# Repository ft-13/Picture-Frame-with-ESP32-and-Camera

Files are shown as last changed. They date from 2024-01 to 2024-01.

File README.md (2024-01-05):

# Picture-Frame-with-ESP32-and-Camera
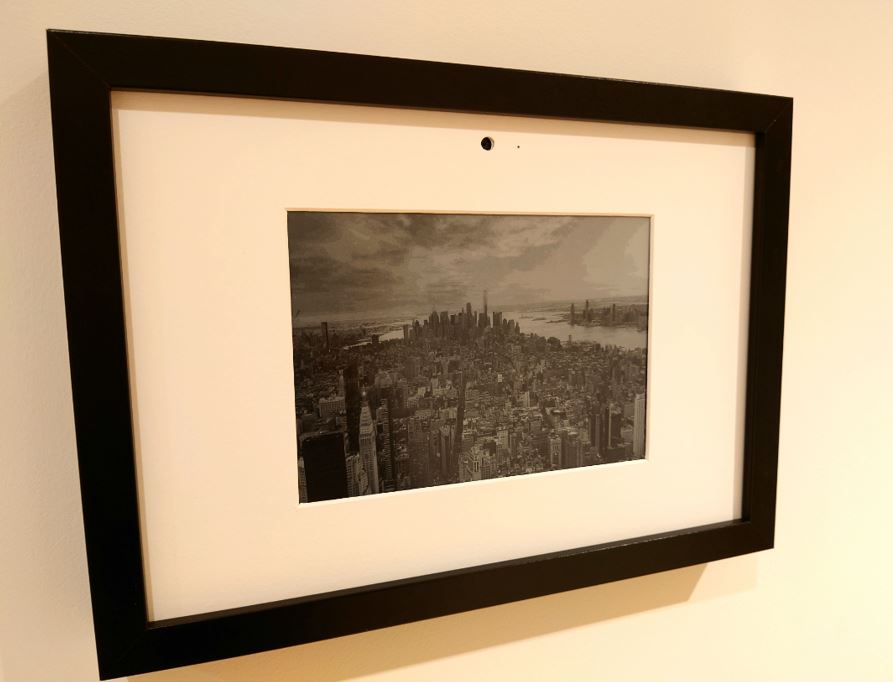
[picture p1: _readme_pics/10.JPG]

The picture frame consists of Firebeetle2 (ESP32-S3) with OV2640 camera, epaper display, powerbank and a self-desined carrier PCB. The whole electronic is mounted on a 3D printed insert. There are 3 Hall sensors attached to the wood of picture frame: top, bottom left and bottom right. µSD card shield is mounted to the carrier PCB and makes it possible to save the camera picture or to load a picture. Using a magnet triggers one of the three Hall sensors and wakes up ESP32 from deep sleep. When the top Hall sensor is triggered, the picture frame takes a picture and sends it to the epeaper and the µSD card. If the left or right sensor is triggered, the previous or next image is loaded from the µSD card to the epeaper display.  
  
Special thanks go to my wife, who has always been very patient with my handicrafts :)



## Software
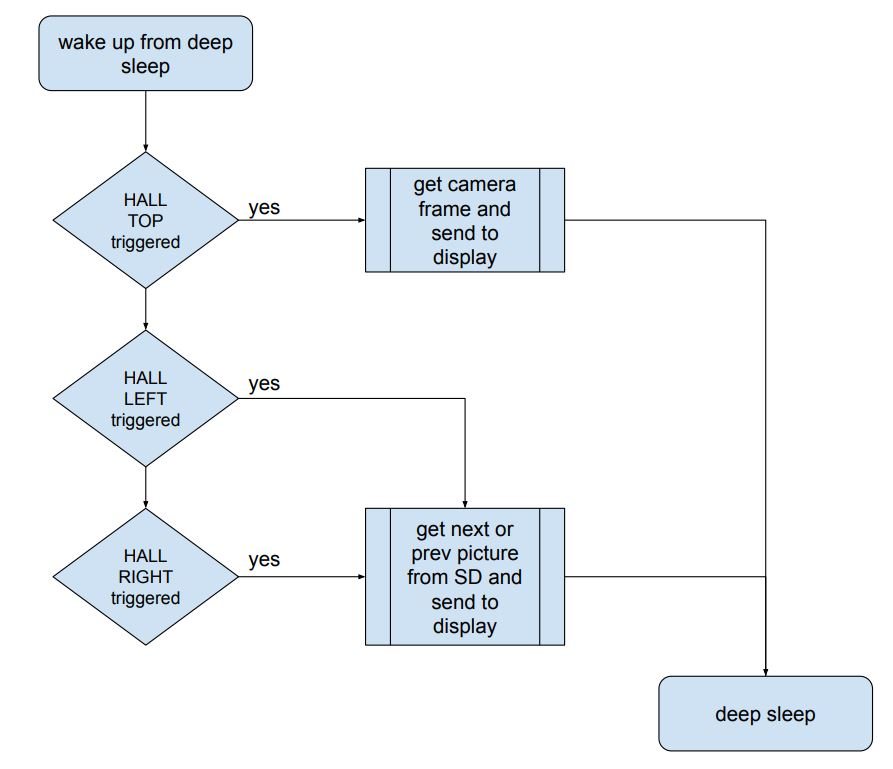
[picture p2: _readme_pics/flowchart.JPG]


## Hardware
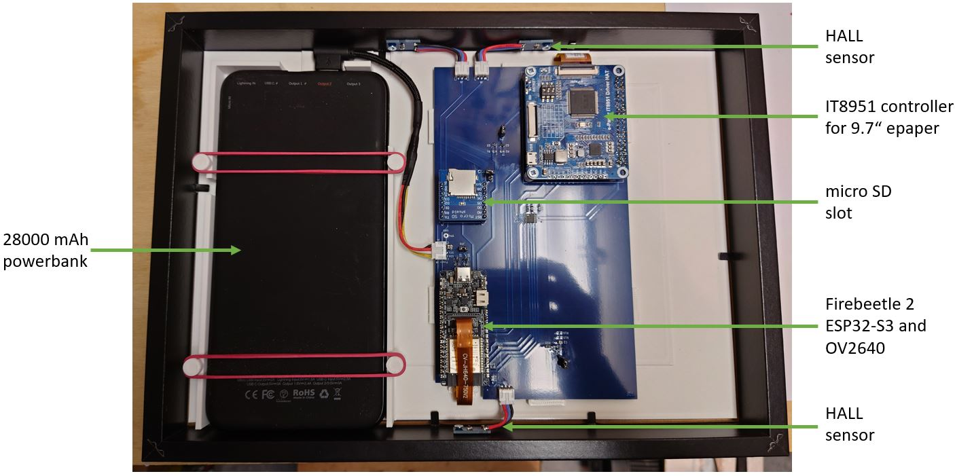
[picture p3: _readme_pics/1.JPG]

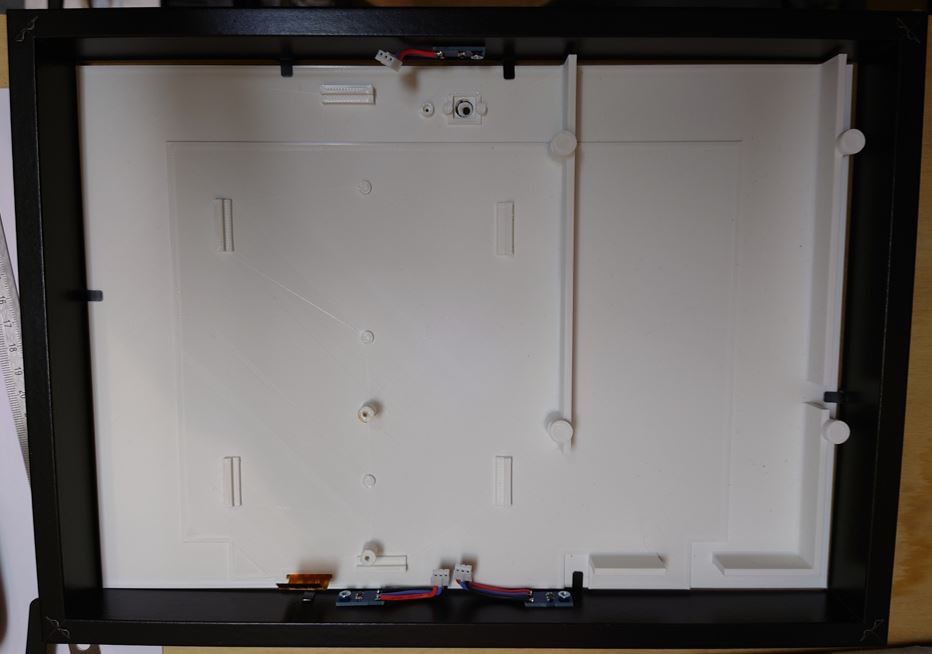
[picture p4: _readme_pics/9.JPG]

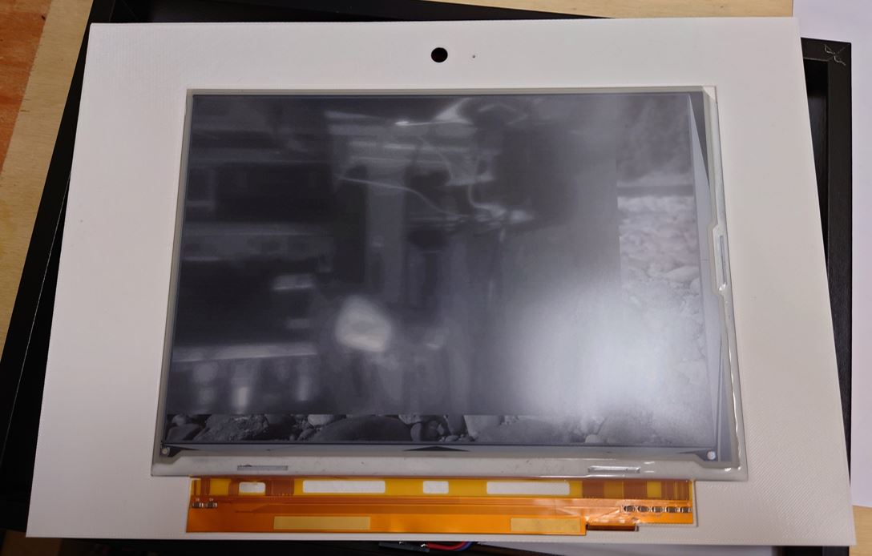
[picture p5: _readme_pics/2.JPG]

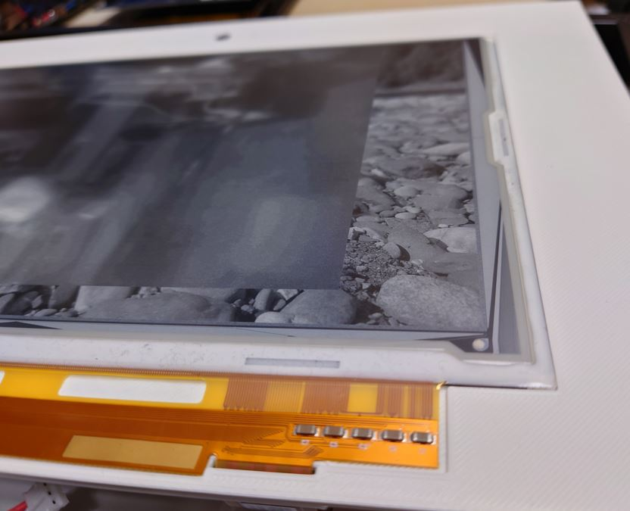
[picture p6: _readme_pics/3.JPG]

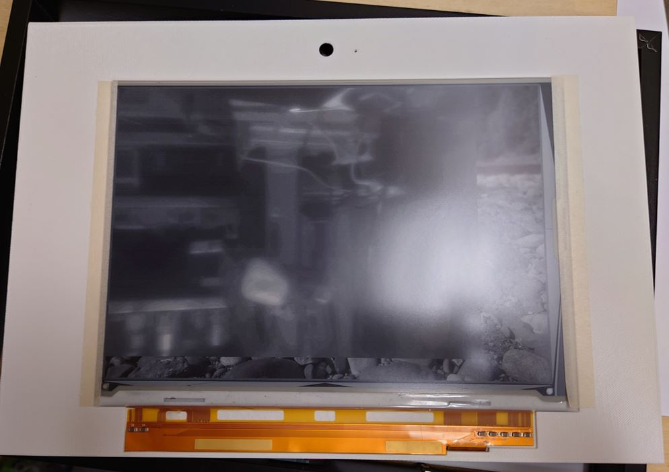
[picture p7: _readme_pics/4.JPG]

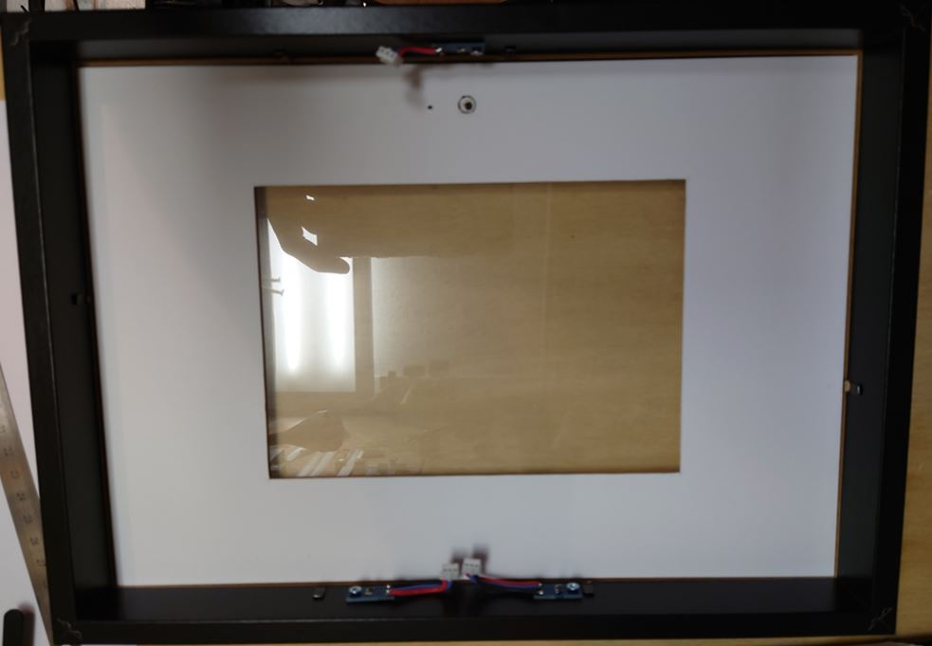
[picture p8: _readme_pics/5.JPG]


### BOM
Part | Description | Link 
--- | --- | ---
Firebeetle2 | ESP32-S3 8MB PSRAM and OV2640 camera | [dfrobot link](https://www.dfrobot.com/product-2677.html)
IT8951 display HAT | - | [Waveshare link](https://www.waveshare.com/9.7inch-e-paper-hat.htm)
epaper display | 1200x825, 9.7inch | [Waveshare datasheet](https://www.waveshare.com/w/upload/f/ff/9.7inch_E-paper_Specification.PDF)
µSD shield | D1 mini shield adapter | [AZ delivery link](https://www.az-delivery.de/products/micro-sd-card-adapter-shield)
Hall sensors | DRV5032FA TI | [TI datasheet](https://www.ti.com/lit/ds/symlink/drv5032.pdf?ts=1704351535372&ref_url=https%253A%252F%252Fwww.google.com%252F)
Analog Switch | TS3A5018PW TI | [TI datasheet](https://www.ti.com/lit/ds/symlink/ts3a5018.pdf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)
Powerbank | Charmast 26800mAh | [Amazon link](https://www.amazon.de/Charmast-Powerbank-Ladeger%C3%A4t-Eing%C3%A4ngen-Smartphones-Schwarz/dp/B073FJ9X2J)
Picture frame | Ikea black 21x30 cm | [Ikea link](https://www.ikea.com/de/de/p/ribba-rahmen-schwarz-60378396/)

### Powerbank
The powerbank has a hugh capacity of 26800mAh. When ESP32 is in deep sleep the entire electronic draws a current of <=2mA. If the current draw from powerbank is about <70mA the powerbank automatically turns off its outputs after 30 seconds. Then the electronic has no chance to power up unless the button of powerbank is pressed to switch it on again. I figured out that the powerbank has two DCDC converters: IP5306 and IP5310. Both chips can be configured via I2C. I found the I2C protocol of IP5306 on github: [github link](https://github.com/bheesma-10/IP5306_I2C) but no chance for IP5310. For IP5306 there is a register bit which can be set to tell the chip to stay on. Unfortunatelly this bit is not the same for IP5310. Why not using IP5306 instead of IP5310? Because I could get access only to I2C pins of IP5310 via charging state LEDs. The next problem is that IP5310 is responsible for battery charging.

I soldered I2C wires to the LEDs which are connected to IP5310 and tried to write to different registers and voila! Bit 7 of register 0x02 tells the chip to stay on.
What else? The powerbank on/off switch is connected to IP5306. As soon as IP5306 wakes up, it will wake up IP5310 via a transitor. Therefore I had to do some modifications on powerbank PCB. Now I can switch IP5310 off and on by pressing the power button of the powerbank (single push: ON, double push: OFF).

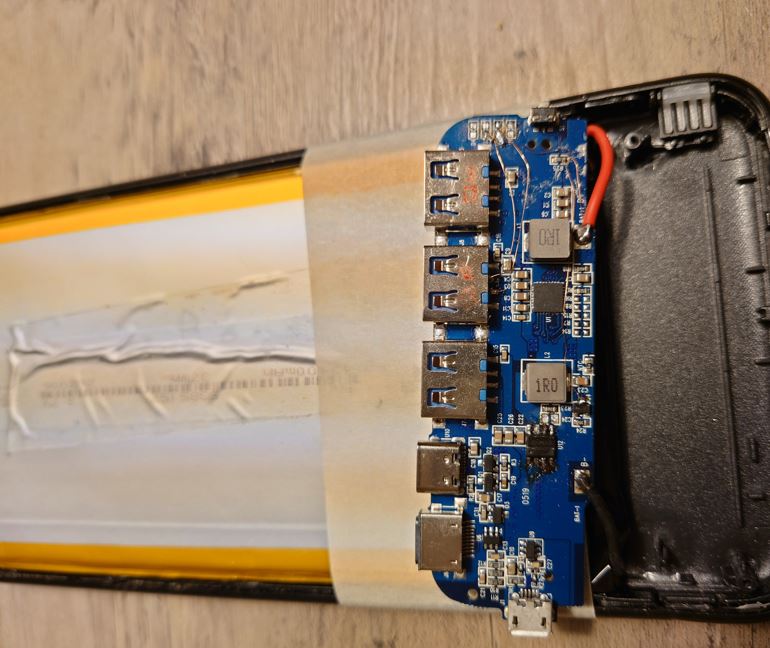
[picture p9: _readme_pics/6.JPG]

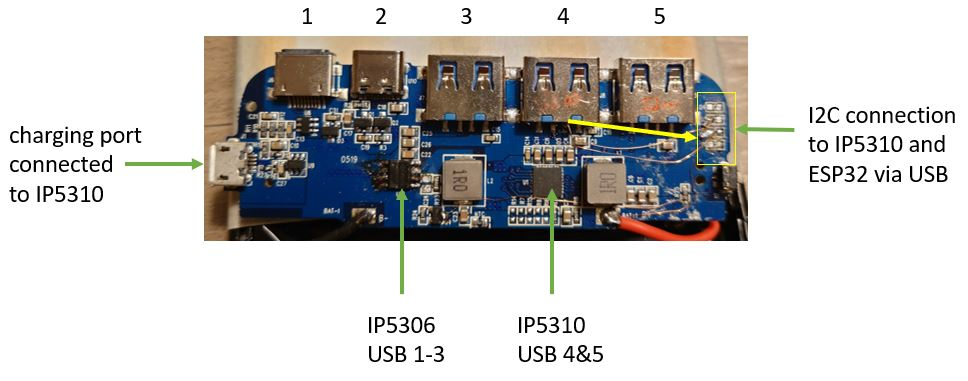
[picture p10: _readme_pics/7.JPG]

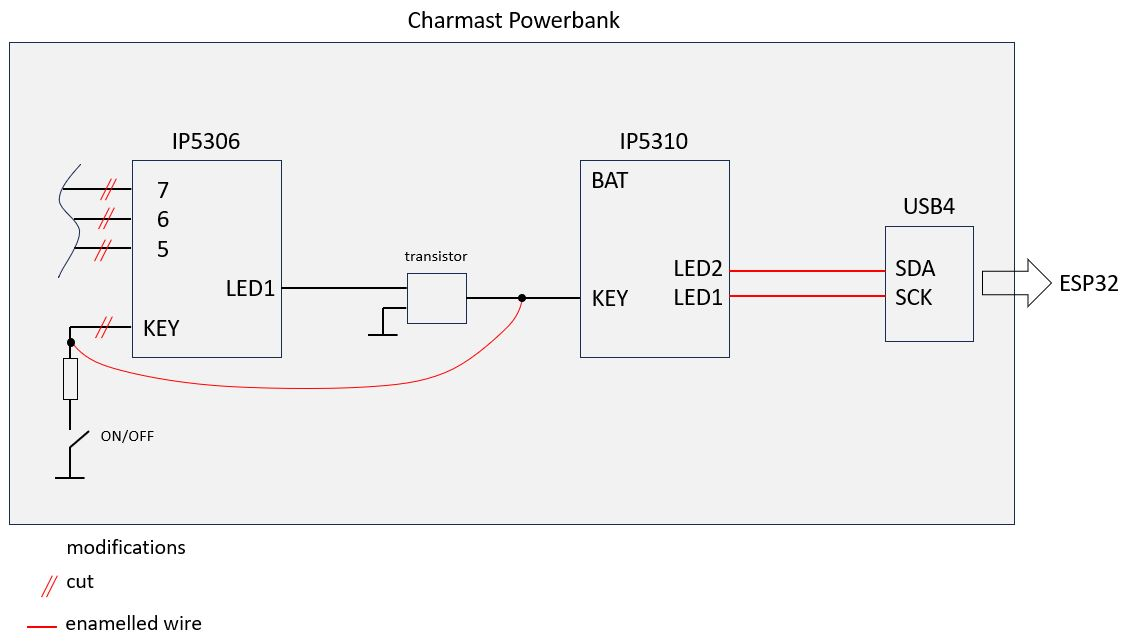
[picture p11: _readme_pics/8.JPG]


### Current Consumption
My goal was it that the powerbank lasts for about 1 year. Of course it depends on how many pictures do you take and how many picture do you load from µSD card.
In deep sleep mode the entire electronic (excluding powerbank) draws a current of about 344µA. Unfortunately, this is not the figure that can be used for the calculation. The IP5310 DCDC converter has a converter efficiency that drives the figure up at the end. That's why I measured the current consumption from the battery itself. The unloaded powerbank draws a current of 1.4mA and in loaded condition (334µA) the current consumption is about 2mA.
If I never took a photo, i.e. ESP32 is in deep sleep all the time, the power bank would last:
days = 26800mAh / 2mA / 24h = 558 days (1.5 years).

But lets make the calculation with some assumptions:  
(I have not yet made any exact measurements, so this is a simplified calculation)
- 1 picture per day and 2 µSD card read access' per day.
- take picture and send to display and µSD card: 300mA for 10s
- load picture from µSD card and send to display: 250mA for 8s
  
We need to know the average current consumption  
Iavg = (300mA * 10s + 250mA * 8s * 2 + 2mA * 3570s) / 3600s = 3.93mA  
to calculate how long the powerbank lasts  
days = 26800mAh / Iavg / 24h = 284 days.
  
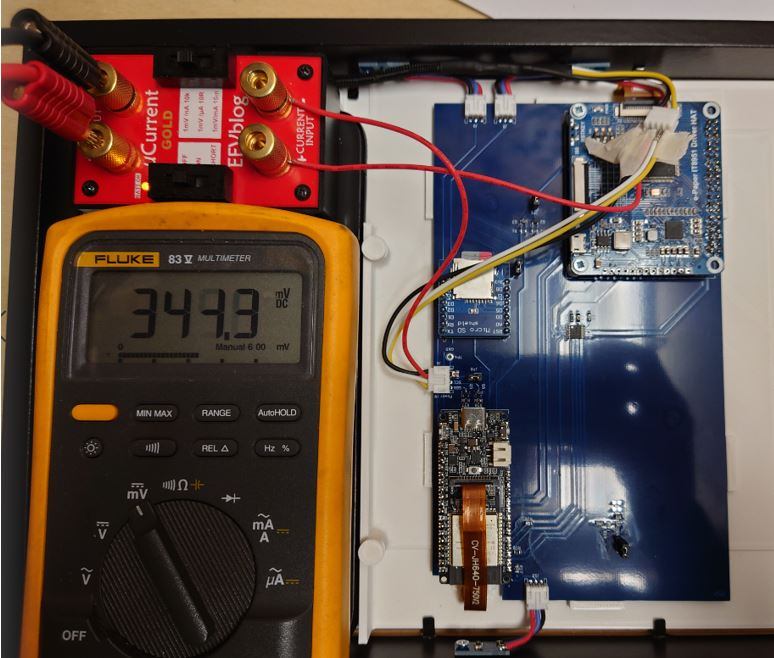
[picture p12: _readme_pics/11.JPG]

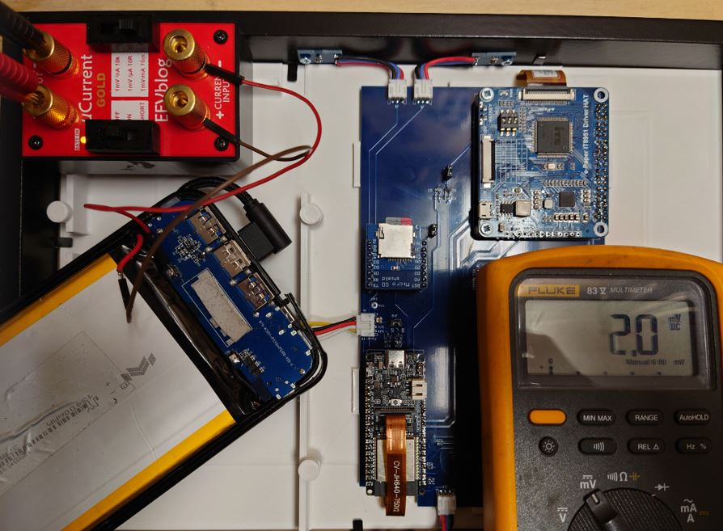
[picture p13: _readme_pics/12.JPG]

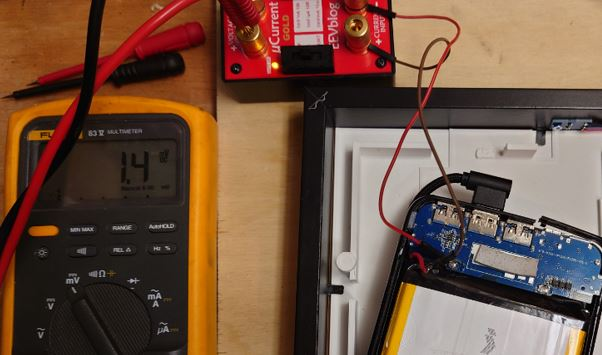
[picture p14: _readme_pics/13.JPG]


## FAQ
1. Why is the carrier PCB so hugh?  
   Firebeetle2 (Camera has short flex PCB) and IT8951 cannot not be postioned on the same side, as the flex PCB of epaper fills the entire bottom side. Therefore there is no space left where the camera could see through.
2. Why did you use Firebeetle2? What's so special about?  
   The Firebeetle2 has a DCDC Converter, which can be configured over I2C and can deactivate the power of the camera, thus bringing the power consumption of the camera to null.
3. Why is the size of the camera picture (XGA 1024x768) smaller than the available size of the display (1200x825)?  
   Because the passpartout cut-out of the picture frame has nearly the size of XGA. Of course I could have bought a passpartout with a larger cut-out, which I will do next.
4. If you have already designed your own PCB, why didn't you include a charging circuit instead of struggling with the power bank?  
   I didn't do much research but I couldn't find a suitable Li-Ion charging IC with integrated boost converter and pass through function.
   I also wanted to keep the development time as short as possible and do without non-SOICs, as I soldered the components on by hand.
   And it was also fun "hacking" the powerbank.
5. Why did you decide to use Hall sensors instead of switches, proximity sensors or even gesture recognition using the camera?  
   The current consumption of the Hall sensors is a maximum of 3.5µA per sensor, as other sensor technologies cannot keep up.
   I wanted to do without electromechanical switches, as the overall picture would not have been nice for me, apart from the fact that I couldn't find any very small built-in pushbuttons.
   Gesture recognition using the ESP camera would have increased power consumption and drastically reduced battery life.
   A capacitive proximity switch consisting of e.g. an AD7151/AD7156 and a capacitive foil would certainly have worked as well, if not more elegantly, but in this case I wanted to save costs as I had the Hall sensors lying around anyway.
6. In which format are the files saved on the SD card or in which format do they have to be?  
   The recorded image is saved as raw bytes with an ascending number and the file extension .txt. The file size is always exactly 768432 bytes (1024x768 pixels and 8bit/pixel). 
7. Is there a way to view the images on the SD card on a PC and is it possible to save images other than those taken by the camera itself?  
   Yes, both are possible. It is possible with the free tool magick e.g. In the repository folder "Software/2_pic_converter" there is a self-written python tool.
   This tool converts all jpg images in a folder and stores them in an "output" folder. These can then simply be copied to the SD card (with ascending number).
   With the command "magick -depth 8 -size 1024x768 gray:files_on_sd_card.txt result.jpg" the raw bytes can be converted back into a jpg image.
   The tool is currently very simple and does not yet have any terminal arguments etc.
8. AI generated pictures?  
   The next upgrade will be for my Raspberry Pi server to generate an image once a day from an AI on the internet and then send it to the picture frame via Wifi.

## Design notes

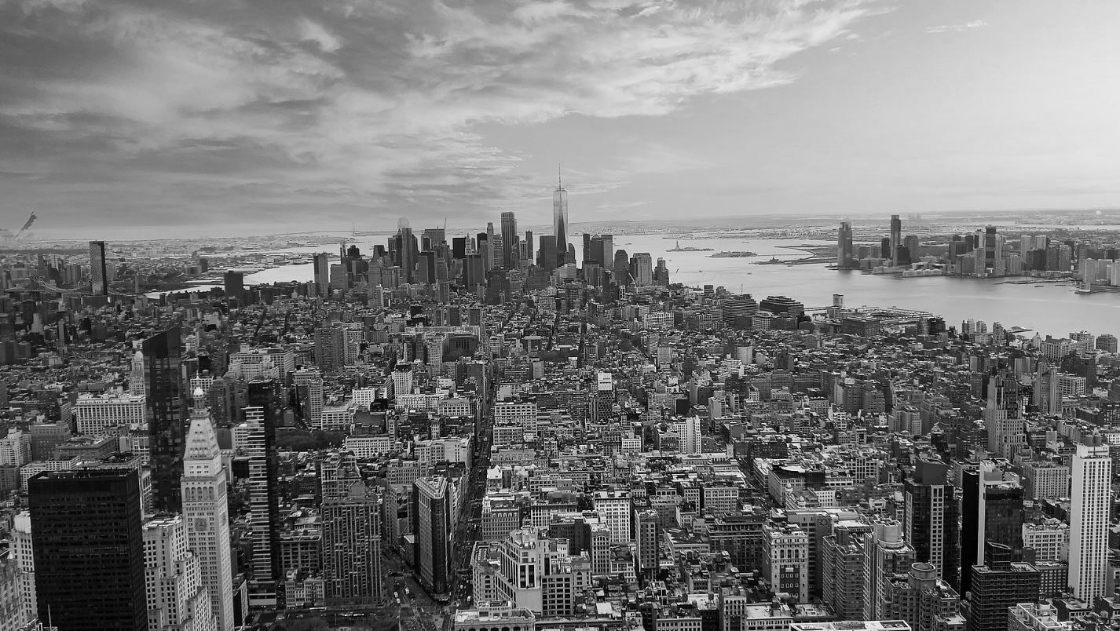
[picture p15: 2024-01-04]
Software/2_pic_converter/converter/manhatten_gray.JPG

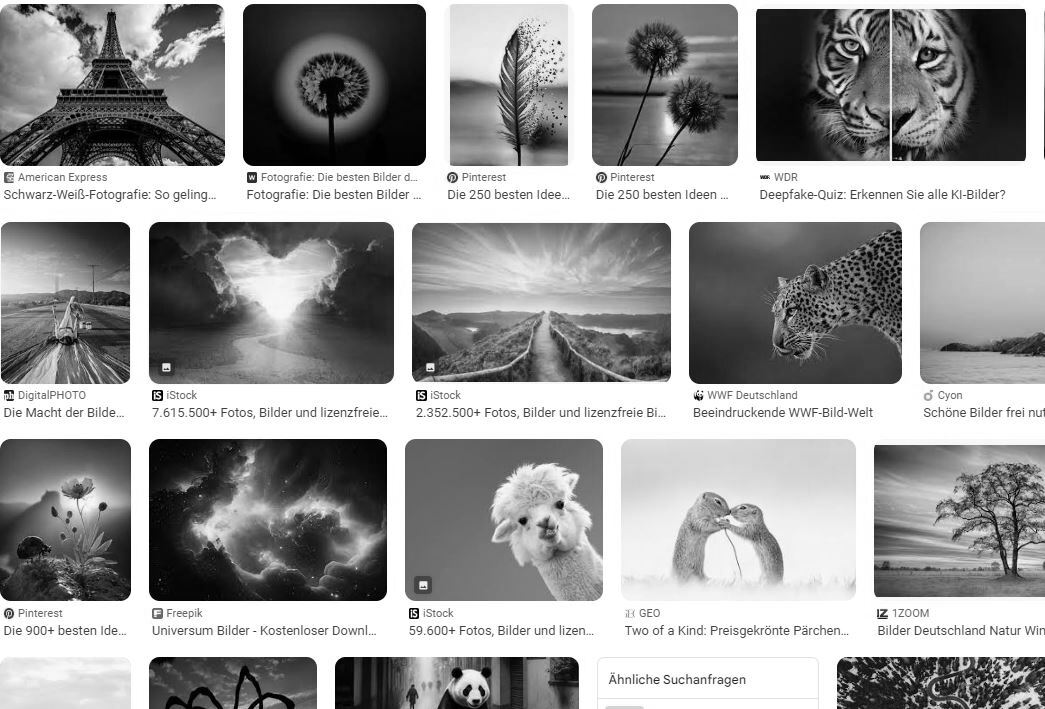
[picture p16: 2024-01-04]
Software/2_pic_converter/converter/google_pics_gray.JPG

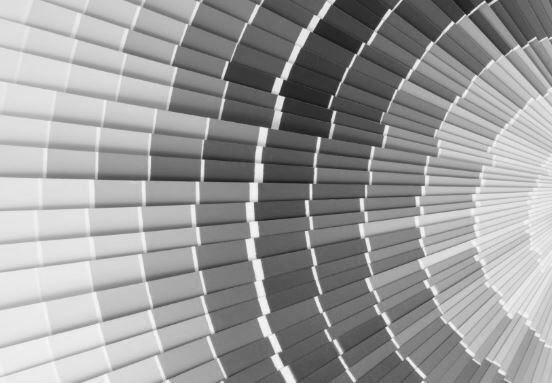
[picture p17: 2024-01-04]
Software/2_pic_converter/converter/color_palette_gray.JPG

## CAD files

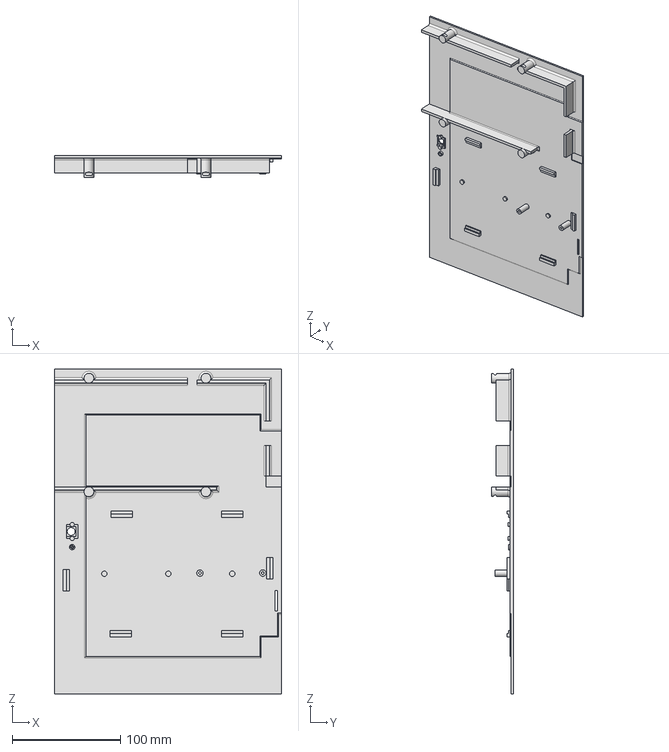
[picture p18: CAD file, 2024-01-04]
Hardware/step/display_holder.stp
210.0 x 20.0 x 300.0 mm

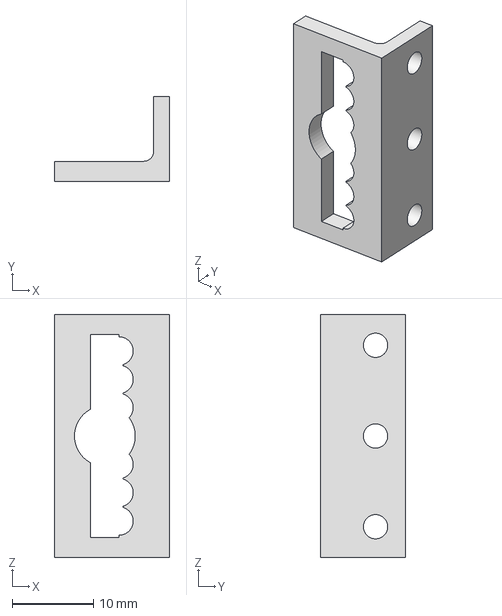
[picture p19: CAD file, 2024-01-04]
Hardware/step/screw_frame_holder.stp
14.3 x 10.5 x 30.0 mm

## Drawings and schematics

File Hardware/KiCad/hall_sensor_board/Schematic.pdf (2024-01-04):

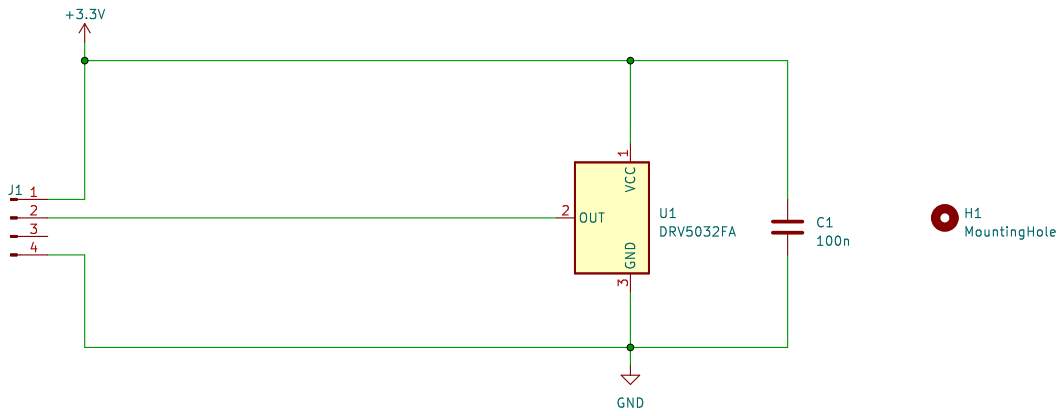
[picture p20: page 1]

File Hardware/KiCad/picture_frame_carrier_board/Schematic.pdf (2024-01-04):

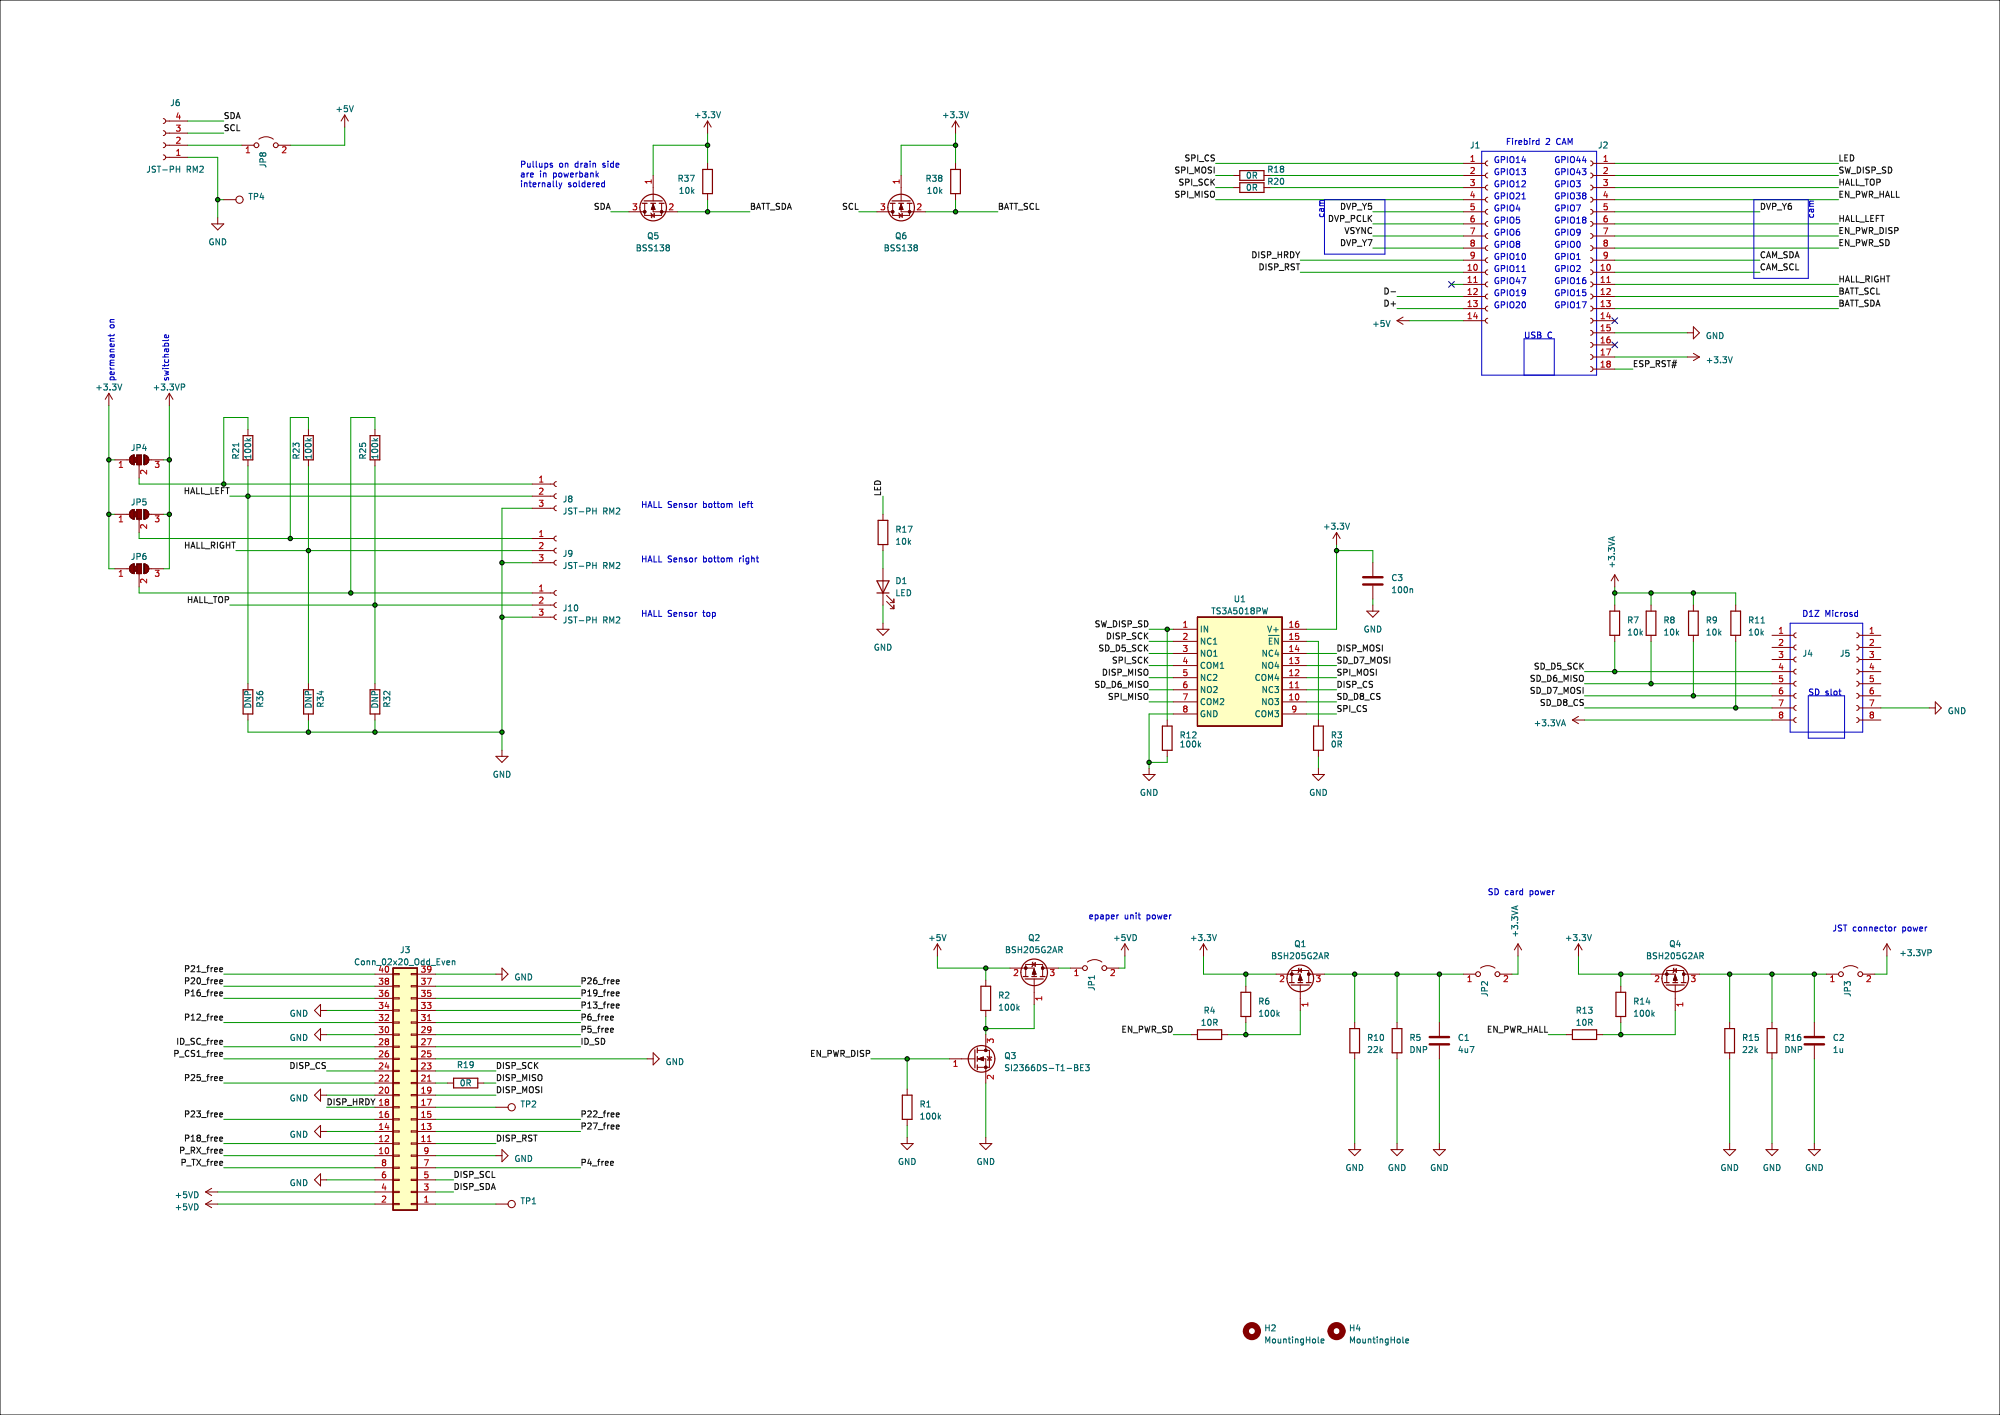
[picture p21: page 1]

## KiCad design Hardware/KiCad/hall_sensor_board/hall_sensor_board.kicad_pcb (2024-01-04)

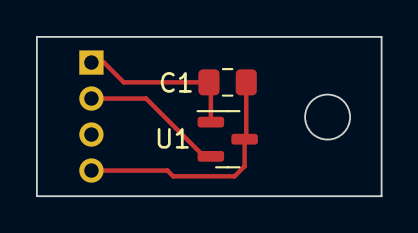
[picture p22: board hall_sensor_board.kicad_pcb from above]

Board: 2 copper layers, 19.2 x 8.9 mm, 3 parts (1 on the bottom side), 3 nets.

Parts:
C1: 100n; C_0805_2012Metric_Pad1.18x1.45mm_HandSolder
J1: Conn_01x04_Pin; PinHeader_1x04_P2.00mm_Horizontal
U1: DRV5032FA; SOT-23

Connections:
+3.3V: C1.1, J1.1, U1.1 (VCC)
GND: C1.2, J1.4, U1.3 (GND)
unnamed: J1.2, U1.2 (OUT)

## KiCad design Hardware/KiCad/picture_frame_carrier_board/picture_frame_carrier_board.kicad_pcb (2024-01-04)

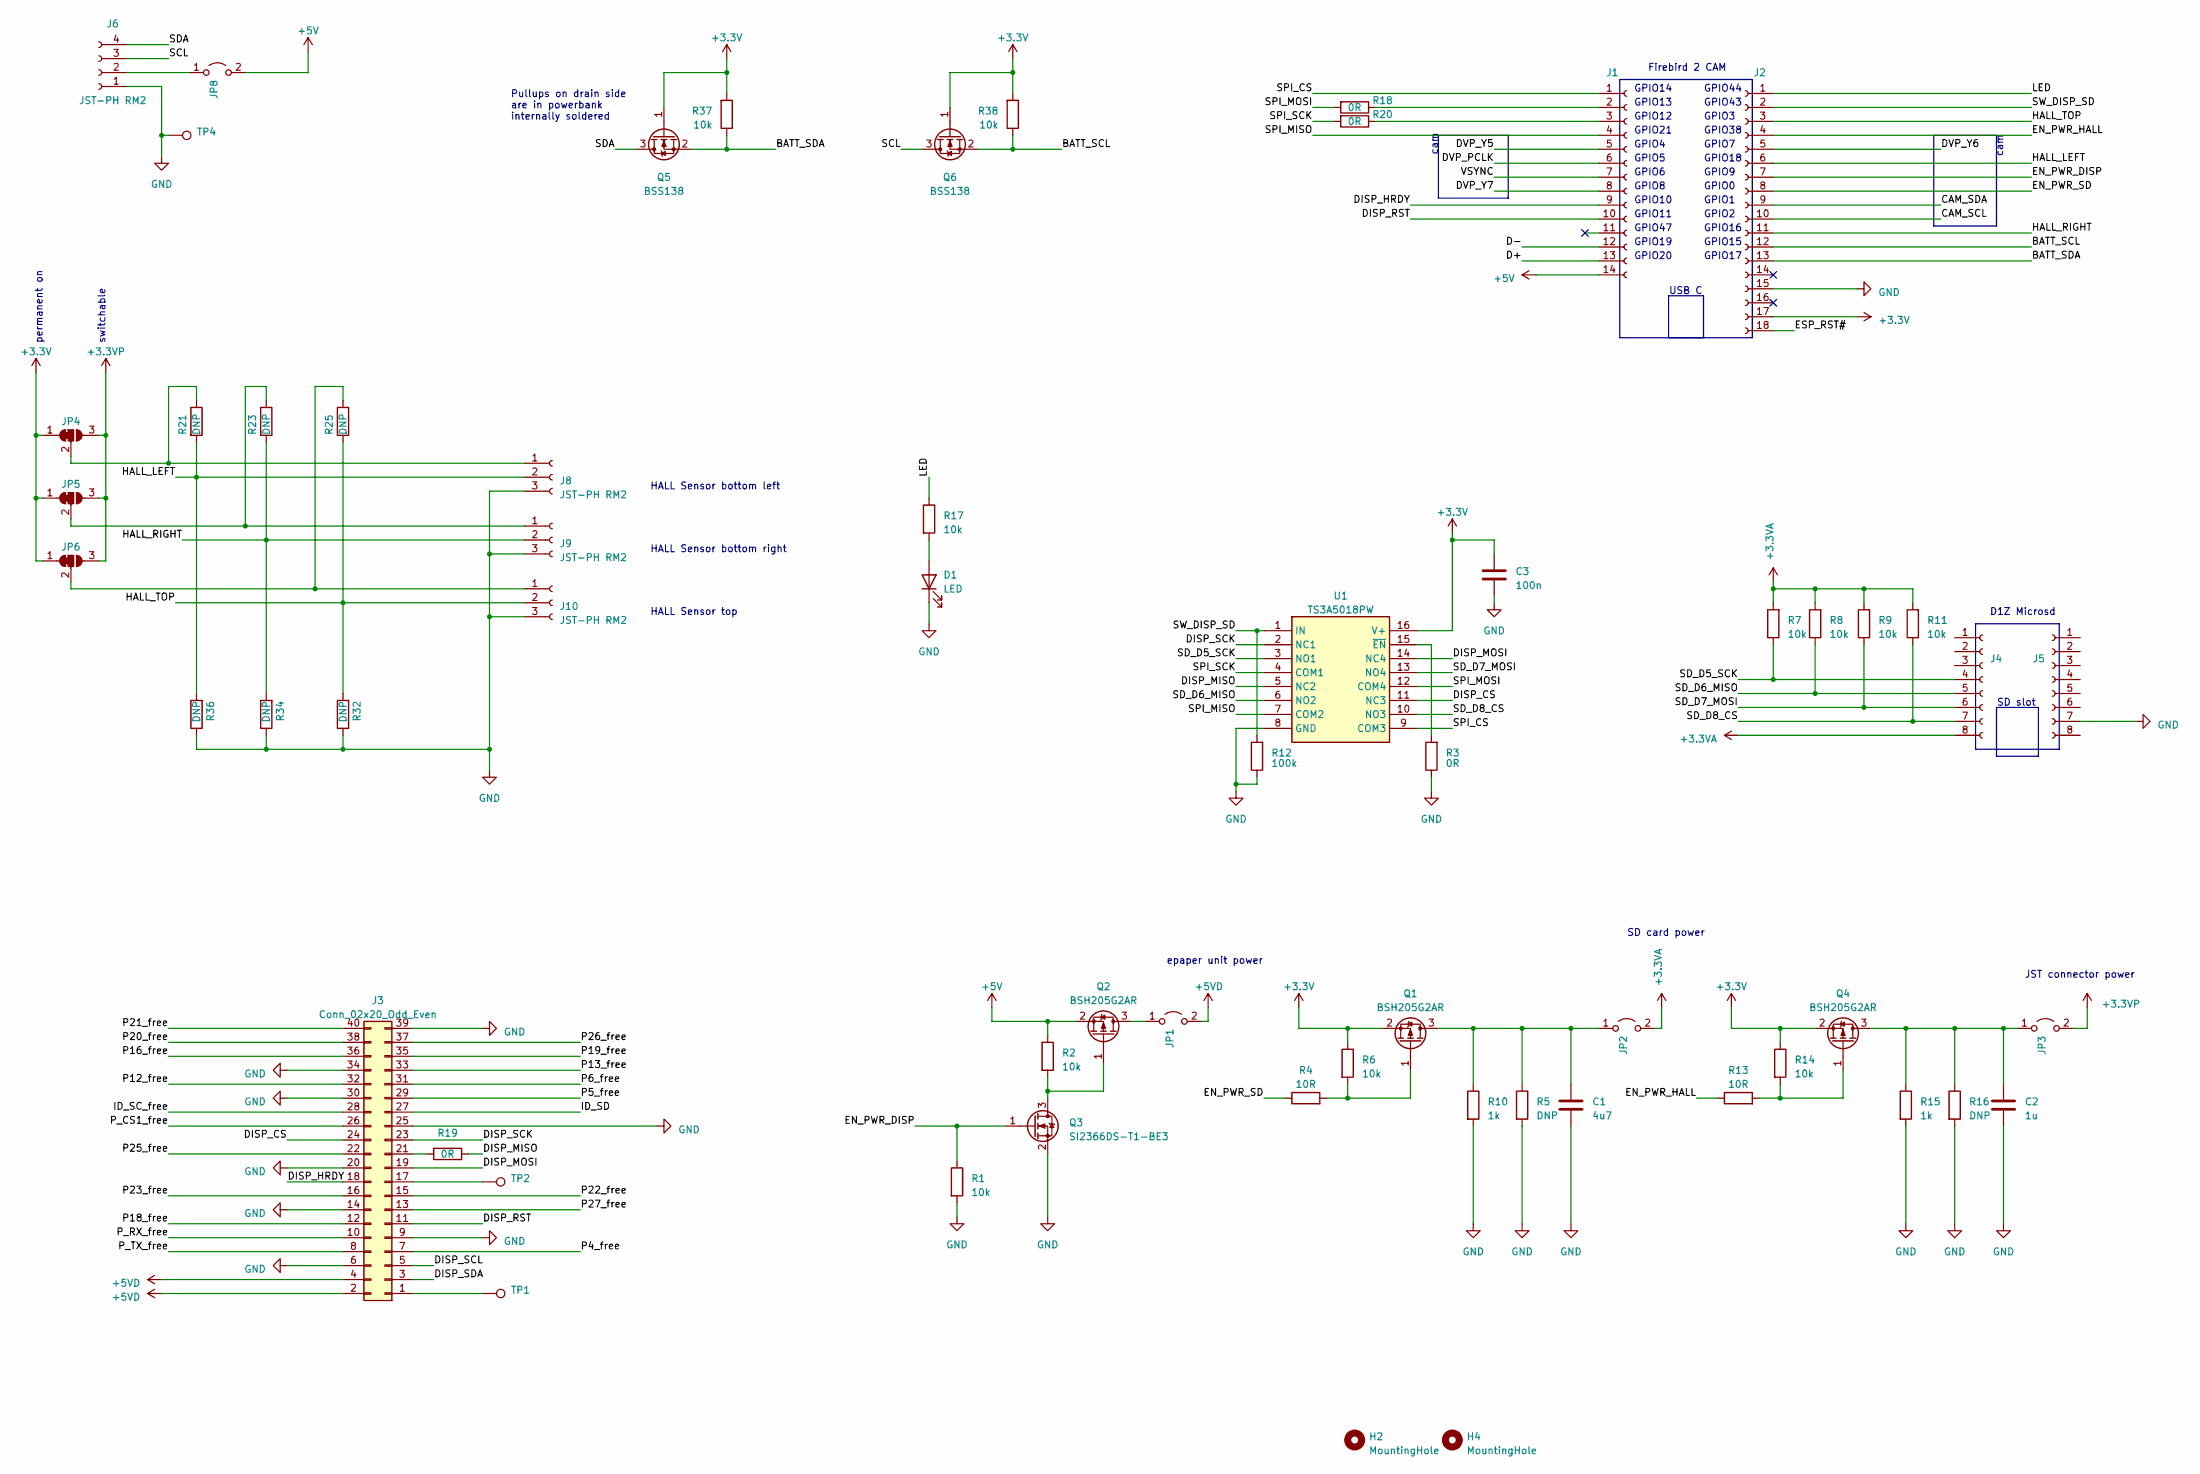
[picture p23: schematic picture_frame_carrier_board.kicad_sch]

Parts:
C1: 4u7; C_0805_2012Metric_Pad1.18x1.45mm_HandSolder
C2: 1u; C_0805_2012Metric_Pad1.18x1.45mm_HandSolder
C3: 100n; C_0805_2012Metric_Pad1.18x1.45mm_HandSolder
D1: LED; LED_0603_1608Metric_Pad1.05x0.95mm_HandSolder
H2, H4: MountingHole; MountingHole_2.7mm_M2.5_DIN965
J1: Conn_01x14_Socket; PinSocket_1x14_P2.54mm_Vertical
J2: Conn_01x18_Socket; PinSocket_1x18_P2.54mm_Vertical
J3: Conn_02x20_Odd_Even; bkl_10122235
J4, J5: Conn_01x08_Socket; PinSocket_1x08_P2.54mm_Vertical
J6: JST-PH RM2; JST_PH_S4B-PH-K_1x04_P2.00mm_Horizontal
J8, J9, J10: JST-PH RM2; JST_PH_S3B-PH-K_1x03_P2.00mm_Horizontal
JP1, JP2, JP3, JP8: Jumper_2_Open; PinHeader_1x02_P2.54mm_Vertical
JP4, JP5, JP6: SolderJumper_3_Bridged12; SolderJumper-3_P1.3mm_Bridged12_Pad1.0x1.5mm_NumberLabels
Q1, Q2, Q4: BSH205G2AR; SOT-23
Q3: SI2366DS-T1-BE3; SOT-23
Q5, Q6: BSS138; SOT-23
R1, R2, R6, R7, R8, R9, R11, R14, R17, R37, R38: 10k; R_0805_2012Metric_Pad1.20x1.40mm_HandSolder
R3, R18, R19, R20: 0R; R_0805_2012Metric_Pad1.20x1.40mm_HandSolder
R4, R13: 10R; R_0805_2012Metric_Pad1.20x1.40mm_HandSolder
R5, R16, R21, R23, R25, R32, R34, R36: DNP; R_0805_2012Metric_Pad1.20x1.40mm_HandSolder
R10, R15: 1k; R_0805_2012Metric_Pad1.20x1.40mm_HandSolder
R12: 100k; R_0805_2012Metric_Pad1.20x1.40mm_HandSolder
TP1, TP2: TestPoint; TestPoint_Pad_1.5x1.5mm
TP4: TestPoint; TestPoint_THTPad_D2.5mm_Drill1.2mm
U1: TS3A5018PW; SOP65P640X120-16N; Mouser Part Number 595-TS3A5018PW

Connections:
+3.3V: C3.1, J2.17, JP4.1 (A), JP5.1 (A), JP6.1 (A), Q1.2 (S), Q4.2 (S), Q5.1 (G), Q6.1 (G), R6.1, R14.1, R37.2, R38.2, U1.16 (V+)
+3.3VA: J4.8, JP2.2 (B), R7.2, R8.2, R9.2, R11.2
+3.3VP: JP3.2 (B), JP4.3 (B), JP5.3 (B), JP6.3 (B)
+5V: J1.14, JP8.2 (B), Q2.2 (S), R2.1
+5VD: J3.2, J3.4, JP1.2 (B)
/BATT_SCL: J2.12, Q6.2 (S), R38.1
/BATT_SDA: J2.13, Q5.2 (S), R37.1
/CAM_SCL: J2.10
/CAM_SDA: J2.9
/D+: J1.13
/D-: J1.12
/DISP_CS: J3.24, U1.11 (NC3)
/DISP_HRDY: J1.9, J3.18
/DISP_MISO: R19.1, U1.5 (NC2)
/DISP_MOSI: J3.19, U1.14 (NC4)
/DISP_RST: J1.10, J3.11
/DISP_SCK: J3.23, U1.2 (NC1)
/DISP_SCL: J3.5
/DISP_SDA: J3.3
/DVP_PCLK: J1.6
/DVP_Y5: J1.5
/DVP_Y6: J2.5
/DVP_Y7: J1.8
/EN_PWR_DISP: J2.7, Q3.1 (G), R1.1
/EN_PWR_HALL: J2.4, R13.1
/EN_PWR_SD: J2.8, R4.1
/ESP_RST#: J2.18
/HALL_LEFT: J2.6, J8.2, R21.2, R36.2
/HALL_RIGHT: J2.11, J9.2, R23.2, R34.2
/HALL_TOP: J2.3, J10.2, R25.2, R32.2
/ID_SC_free: J3.28
/ID_SD: J3.27
/LED: J2.1, R17.1
/P4_free: J3.7
/P5_free: J3.29
/P6_free: J3.31
/P12_free: J3.32
/P13_free: J3.33
/P16_free: J3.36
/P18_free: J3.12
/P19_free: J3.35
/P20_free: J3.38
/P21_free: J3.40
/P22_free: J3.15
/P23_free: J3.16
/P25_free: J3.22
/P26_free: J3.37
/P27_free: J3.13
/P_CS1_free: J3.26
/P_RX_free: J3.10
/P_TX_free: J3.8
/SCL: J6.3, Q6.3 (D)
/SDA: J6.4, Q5.3 (D)
/SD_D5_SCK: J4.4, R7.1, U1.3 (NO1)
/SD_D6_MISO: J4.5, R8.1, U1.6 (NO2)
/SD_D7_MOSI: J4.6, R9.1, U1.13 (NO4)
/SD_D8_CS: J4.7, R11.1, U1.10 (NO3)
/SPI_CS: J1.1, U1.9 (COM3)
/SPI_MISO: J1.4, U1.7 (COM2)
/SPI_MOSI: R18.2, U1.12 (COM4)
/SPI_SCK: R20.2, U1.4 (COM1)
/SW_DISP_SD: J2.2, R12.2, U1.1 (IN)
/VSYNC: J1.7
GND: C1.2, C2.2, C3.2, D1.1 (K), J2.15, J3.6, J3.9, J3.14, J3.20, J3.25, J3.30, J3.34, J3.39, J5.7, J6.1, J8.3, J9.3, J10.3, Q3.2 (S), R1.2, R3.1, R5.2, R10.2, R12.1, R15.2, R16.2, R32.1, R34.1, R36.1, TP4.1, U1.8 (GND)
unnamed: D1.2 (A), R17.2
unnamed: J1.2, R18.1
unnamed: J1.3, R20.1
unnamed: J3.1, TP1.1
unnamed: J3.17, TP2.1
unnamed: J3.21, R19.2
unnamed: J6.2, JP8.1 (A)
unnamed: J8.1, JP4.2 (C), R21.1
unnamed: J9.1, JP5.2 (C), R23.1
unnamed: J10.1, JP6.2 (C), R25.1
unnamed: JP1.1 (A), Q2.3 (D)
unnamed: C1.1, JP2.1 (A), Q1.3 (D), R5.1, R10.1
unnamed: C2.1, JP3.1 (A), Q4.3 (D), R15.1, R16.1
unnamed: Q1.1 (G), R4.2, R6.2
unnamed: Q2.1 (G), Q3.3 (D), R2.2
unnamed: Q4.1 (G), R13.2, R14.2
unnamed: R3.2, U1.15 (~EN)

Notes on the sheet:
cam
GPIO18
GPIO7
GPIO5
JST connector power
GPIO6
GPIO15
HALL Sensor top
D1Z Microsd
GPIO44
GPIO1
GPIO2
HALL Sensor bottom right
GPIO4
GPIO47
GPIO8
SD slot
SD card power
GPIO38
Firebird 2 CAM
GPIO13
GPIO10
GPIO11
epaper unit power
GPIO9
GPIO17
GPIO3
GPIO16
HALL Sensor bottom left
GPIO12
USB C
GPIO21
permanent on
GPIO0
GPIO43
switchable
GPIO14
GPIO19
GPIO20
Pullups on drain side are in powerbank internally soldered

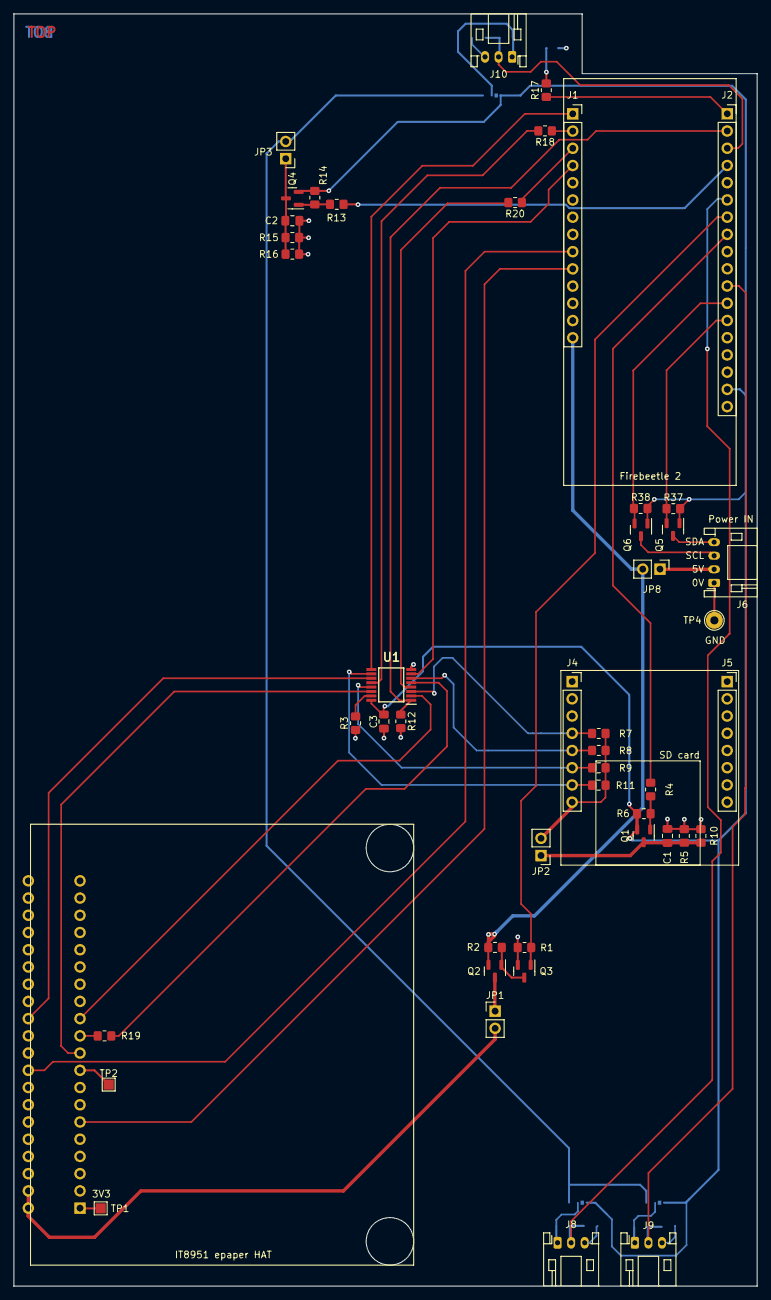
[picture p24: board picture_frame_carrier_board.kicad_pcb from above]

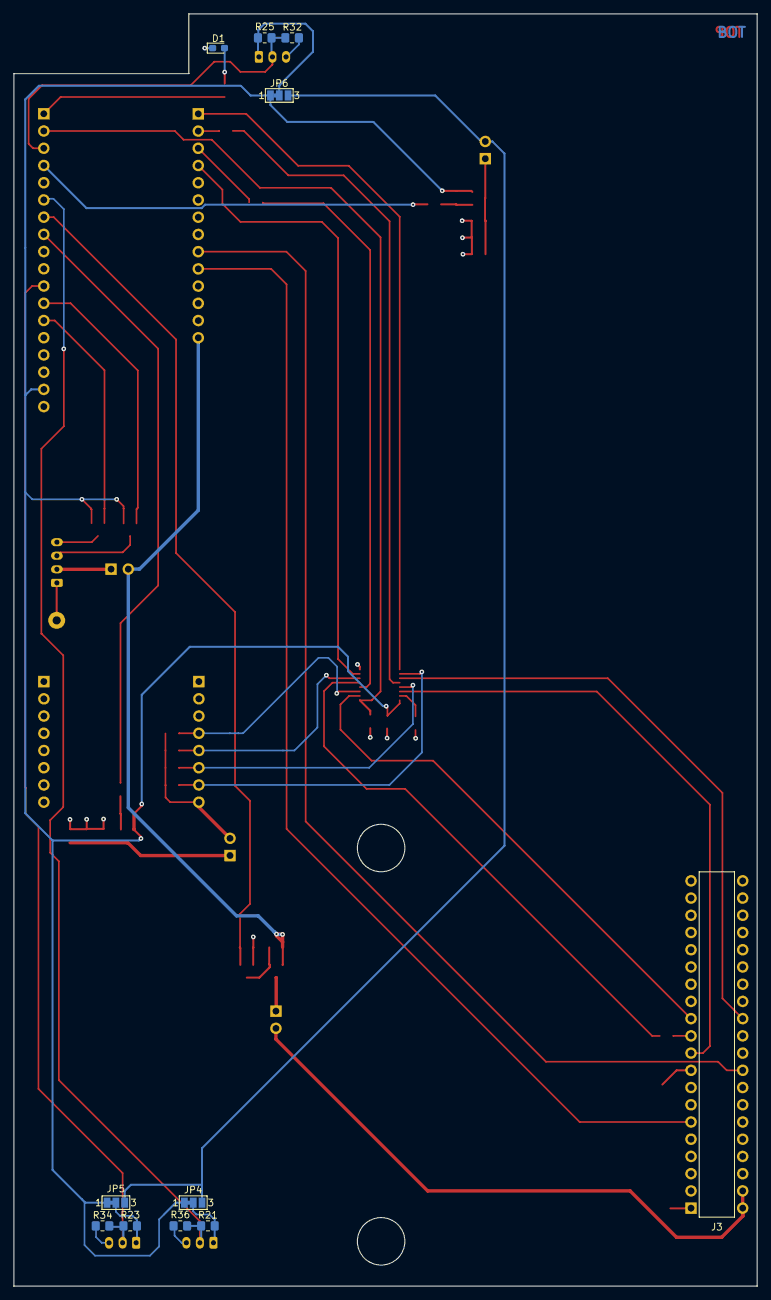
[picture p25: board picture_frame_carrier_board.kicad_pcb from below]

Board: 4 copper layers, 109.6 x 187.6 mm, 60 parts (11 on the bottom side), 49 nets.

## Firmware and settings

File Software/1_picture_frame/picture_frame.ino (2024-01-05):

#include "SPI.h"
#include "FS.h"
#include "SD.h"
#include "DFRobot_AXP313A.h"
#include "esp_camera.h"
#include "it8951.h"
#include "picture_frame.h"

#define GPIO_WAKE_UP_HALL_TOP   HALL_TOP
#define GPIO_WAKE_UP_HALL_LEFT  HALL_LEFT
#define GPIO_WAKE_UP_HALL_RIGHT HALL_RIGHT
#define NEXT                    1
#define PREV                    0
#define OFF                     LOW
#define ON                      HIGH
#define ENABLE_HALL             LOW
#define ENABLE_SD               LOW
#define ENABLE_DISP             HIGH
#define DISABLE_HALL            HIGH
#define DISABLE_SD              HIGH
#define DISABLE_DISP            LOW
// camera frame size XGA and
// grayscale (8bpp)
#define CAMERA_FRAME_SIZE_XGA   786432 // OV2640 XGA 1024x768=786432


DFRobot_AXP313A axp;                                        // For i2c for DCDC converter on Firebeetle2 board to set camera power on/off 
SPIClass spi = SPIClass(HSPI);                              // SPI for epaper display and µSD card
RTC_DATA_ATTR bool is_batt_via_i2c_configured = false;      // preservation of powerbank permanently ON configuration
RTC_DATA_ATTR int32_t g_sd_file_pos = 1;                    // preservation of current µSD card file position

void blink_led_active(void);                                // magnet detected (HALL sensors) -> ESP32 wakeup indication
void blink_led_error(void);                                 // error detected (no SD card, camera/IT8951 init failed etc)
void write_data_batt(uint8_t, uint8_t, uint8_t);            // write i2c data to powerbank (permanent ON command)
uint8_t camera_init(void);
void cam_pic_to_sd_and_disp(void);                          // get camera frame and send to epaper display and save to µSD card
void pic_from_sd_to_disp(uint8_t);                          // left or right HALL sensor triggered -> load previous (HALL left) or next (HALL right) 
                                                            // picture from µSD card and send to epaper display
uint8_t get_wake_up_gpio_num(void);                         // get GPIO number (1 of 3 HALL sensors) from where ESP32 was woken up from deep sleep
uint8_t get_file_buffer(byte*, SDFS, uint32_t, uint8_t);    // get next or previous file from µSD card
uint8_t sd_write_file(SDFS, uint8_t *, size_t);             // save camera frame to µSD card
uint8_t get_sd_file_num(SDFS, uint32_t*);                   // counts number of files on µSD card

void setup(){
  
  Serial.begin(115200);
  //delay(3000);
  //Serial.println("\n\n\n");
  
  //pinMode(EN_PWR_HALL, OUTPUT);
  pinMode(EN_PWR_DISP, OUTPUT);
  pinMode(EN_PWR_SD, OUTPUT);
  pinMode(LED_SHOT, OUTPUT);
  pinMode(SW_DISP_SD, OUTPUT);                              // analog switch to switch between epaper display and µSD card SPI; low: display, high: µSD
  pinMode(HALL_TOP, INPUT);
  pinMode(HALL_LEFT, INPUT);
  pinMode(HALL_RIGHT, INPUT);

  digitalWrite(LED_SHOT, OFF);
  digitalWrite(EN_PWR_SD, ENABLE_SD);                       // µSD power on
  digitalWrite(EN_PWR_DISP, ENABLE_DISP);                   // epaper display power on

  // send permanent ON command to powerbank
  // after power cycle
  if(!is_batt_via_i2c_configured) {
    Wire1.begin(BATT_SDA, BATT_SCL);
    write_data_batt(BATT_IP5310_ADDRESS, \
      BATT_IP5310_REG, BATT_IP5310_VALUE);
    Wire1.end();
    is_batt_via_i2c_configured = true;
  }
    
  spi.begin(SCK, MISO, MOSI, CS);
}


void loop(){

  // figure out what HALL sensor was triggered 
  switch(get_wake_up_gpio_num()){
    case GPIO_WAKE_UP_HALL_TOP:
      blink_led_active();
      cam_pic_to_sd_and_disp();
      break;
    case GPIO_WAKE_UP_HALL_LEFT:
      blink_led_active();
      pic_from_sd_to_disp(NEXT);
      break; 
    case GPIO_WAKE_UP_HALL_RIGHT:
      blink_led_active();
      pic_from_sd_to_disp(PREV);
      break;
    default: break;
  }
  
  esp_sleep_enable_ext1_wakeup(DEEP_SLEEP_BITMASK, ESP_EXT1_WAKEUP_ALL_LOW);  // set ESP32 (ext1) deep sleep GPIO bitmask
  esp_deep_sleep_start();                                                     // keep in mind that ESP32 begins its code from the beginning after wake up from deep sleep
}


void cam_pic_to_sd_and_disp(){
  
  camera_fb_t *fb = NULL;

  spi.beginTransaction(SPISettings(24000000, MSBFIRST, SPI_MODE0));
  if(!IT8951_Init()){
    blink_led_error();
    return;      
  }
  if(!camera_init()){
    blink_led_error();
    return;
  }

  digitalWrite(LED_SHOT, ON);

  // get 5 frames for camera settling
  for(uint8_t i=0; i<1; i++){ // but 1 frame seems enough
    fb = esp_camera_fb_get();
    while (!fb);
    esp_camera_fb_return(fb);
  }
  fb = esp_camera_fb_get();
  while (!fb);
    
  //Serial.printf("len %i\n", (*fb).len);
  digitalWrite(LED_SHOT, OFF);
  digitalWrite(SW_DISP_SD, LOW);
  display_buffer(fb->buf, DISP_OFFSET_X, DISP_OFFSET_Y, fb->width, fb->height); // send frame (picture) to epaper display
  spi.endTransaction();                                                         // stop using SPI bus to allow µSD card using the bus 

  digitalWrite(SW_DISP_SD, HIGH);
  delay(100);
  if (!SD.begin(CS, spi, 24000000)){
    blink_led_error();
    SD.end();
    return;
  }

  if(!sd_write_file(SD, fb->buf, fb->len)){
    blink_led_error();
    SD.end();
    return;
  }
  SD.end();

  // DCDC converter (axp) on firebeetle2 board has a I2C interface.
  // DCDC converter and camera are connected to the same I2C bus.
  // Obvisously camera_init reinitializes I2C peripheral and DCDC converter is not accessible after camera_init.
  // Workaround: Wire.end() and axp.begin again.
  Wire.end(); 
  while(axp.begin() != 0){
    blink_led_error();
    return;
  }
  axp.disablePower(); // disable camera power to save current consumption
}


void pic_from_sd_to_disp(uint8_t ts){
  
  uint32_t file_cnt = 0;
    
  //Serial.println(ESP.getPsramSize() - ESP.getFreePsram());
  byte* psdRamBuffer = (byte*)ps_malloc(CAMERA_FRAME_SIZE_XGA); // allocate bytes in PSRAM
  //Serial.println(ESP.getPsramSize() - ESP.getFreePsram());
  //Serial.println(ESP.getFreePsram());
    
  digitalWrite(SW_DISP_SD, HIGH);
  delay(100);
  if (!SD.begin(CS, spi, 24000000)){
    blink_led_error();
    return;
    esp_deep_sleep_start();
  }

  if(!get_sd_file_num(SD, &file_cnt)){
    blink_led_error();
    SD.end();
    return;     
  }
  if(file_cnt != 0){
    if(!get_file_buffer(psdRamBuffer, SD, file_cnt, ts)){
      blink_led_error();
      SD.end();
      return;
    }
    SD.end();

    spi.beginTransaction(SPISettings(24000000, MSBFIRST, SPI_MODE0));
    digitalWrite(SW_DISP_SD, LOW);
    delay(100);
    if(!IT8951_Init()){
      blink_led_error();
      return;
    }
    
    digitalWrite(LED_SHOT, ON);
    digitalWrite(SW_DISP_SD, LOW);
    display_buffer(psdRamBuffer, DISP_OFFSET_X, DISP_OFFSET_Y, 1024, 768);
    digitalWrite(LED_SHOT, OFF);
    spi.endTransaction();
    spi.end();
  } else {
    SD.end();
  }
}


uint8_t sd_write_file(SDFS SD, uint8_t * buf, size_t len){
  
  char str[20];
  uint32_t file_num = 0;
    
  if(!get_sd_file_num(SD, &file_num)){
    blink_led_error();
    return STAT_ERR;      
  }
  file_num++;
  g_sd_file_pos = file_num; // update global file pos
  sprintf(str, "/%d.txt", file_num);
    
  File file = SD.open(str, FILE_WRITE);
  if(!file){
    blink_led_error();
    return STAT_ERR;
  }
    
  file.write(buf, len); // save camera frame on µSD card (raw bytes)
  file.close();

  return STAT_OK;
}


uint8_t get_file_buffer(byte* buff, SDFS SD, uint32_t file_cnt, uint8_t ts){
  
  char str[20];
  
  if(ts == NEXT){                         // next picture on µSD card
    g_sd_file_pos++;
    if(g_sd_file_pos > file_cnt){         // if value is higher than counted number of files on µSD card
      g_sd_file_pos = 1;                  // start from beginning
    }
  }else{                                  // prev picture on µSD card  
    g_sd_file_pos--;
    if(g_sd_file_pos <= 0){               
      g_sd_file_pos = file_cnt;           // start from last file
    }
  }

  sprintf(str, "/%d.txt", g_sd_file_pos); // all pictures are saved in x.txt format, x = increasing number
  File file = SD.open(str, FILE_READ);
  if(!file){
    file.close();
    blink_led_error();
    return STAT_ERR;
  }
  file.read(buff, CAMERA_FRAME_SIZE_XGA);
  file.close();

  return STAT_OK;
}


uint8_t get_sd_file_num(SDFS SD, uint32_t* p_nf){

  int32_t num_files = 0;
  
  File root = SD.open("/");
  if(!root){
    root.close();
    blink_led_error();
    return STAT_ERR;    
  }

  while(true){
    File entry = root.openNextFile();
    if(!entry){
      break;
    }else{
      num_files++;
    }
  }
  root.rewindDirectory();
  root.close();
  num_files--; // minus because "system volume information" is also counted
  if(num_files < 0)
    num_files = 0;

  *p_nf = (uint32_t)num_files;
  
  return STAT_OK;
}


uint8_t get_wake_up_gpio_num(){
  
  uint64_t gpio_reason = esp_sleep_get_ext1_wakeup_status();
  return (log(gpio_reason))/log(2);
 
  //Serial.print("GPIO that triggered the wake up: GPIO ");
  //Serial.println((log(GPIO_reason))/log(2), 0);
}


void write_data_batt(uint8_t slave_address,uint8_t register_address,uint8_t data){
  
  Wire1.beginTransmission(slave_address);
  Wire1.write(register_address);
  Wire1.write(data);
  Wire1.endTransmission();
}


uint8_t camera_init(){
  
  while(axp.begin() != 0){
    blink_led_error();
    return STAT_ERR;
  }
  axp.enableCameraPower(axp.eOV2640);
  
  camera_config_t config;
  config.ledc_channel = LEDC_CHANNEL_0;
  config.ledc_timer = LEDC_TIMER_0;
  config.pin_d0 = Y2_GPIO_NUM;
  config.pin_d1 = Y3_GPIO_NUM;
  config.pin_d2 = Y4_GPIO_NUM;
  config.pin_d3 = Y5_GPIO_NUM;
  config.pin_d4 = Y6_GPIO_NUM;
  config.pin_d5 = Y7_GPIO_NUM;
  config.pin_d6 = Y8_GPIO_NUM;
  config.pin_d7 = Y9_GPIO_NUM;
  config.pin_xclk = XCLK_GPIO_NUM;
  config.pin_pclk = PCLK_GPIO_NUM;
  config.pin_vsync = VSYNC_GPIO_NUM;
  config.pin_href = HREF_GPIO_NUM;
  config.pin_sscb_sda = SIOD_GPIO_NUM;
  config.pin_sscb_scl = SIOC_GPIO_NUM;
  config.pin_pwdn = PWDN_GPIO_NUM;
  config.pin_reset = RESET_GPIO_NUM;
  config.xclk_freq_hz = 12000000;//10000000; //9MHz war ok
  config.frame_size = FRAMESIZE_XGA; // 1024x768
  config.pixel_format = PIXFORMAT_GRAYSCALE;//PIXFORMAT_JPEG; // for streaming
  //config.pixel_format = PIXFORMAT_RGB565; // for face detection/recognition
  config.grab_mode = CAMERA_GRAB_LATEST;//CAMERA_GRAB_WHEN_EMPTY;
  config.fb_location = CAMERA_FB_IN_PSRAM;
  config.fb_count = 1;

  // if PSRAM IC present, init with UXGA resolution and higher JPEG quality
  //                      for larger pre-allocated frame buffer.
  /*if(config.pixel_format == PIXFORMAT_JPEG){
    if(psramFound()){
      config.jpeg_quality = 10;
      config.fb_count = 2;
      config.grab_mode = CAMERA_GRAB_LATEST;
    } else {
      // Limit the frame size when PSRAM is not available
      config.frame_size = FRAMESIZE_XGA;//FRAMESIZE_SVGA;
      config.fb_location = CAMERA_FB_IN_DRAM;
    }
  } else {
    // Best option for face detection/recognition
    config.frame_size = FRAMESIZE_XGA;
#if CONFIG_IDF_TARGET_ESP32S3
    config.fb_count = 1;
    //config.grab_mode = CAMERA_GRAB_LATEST;
#endif
  }*/

/*#if defined(CAMERA_MODEL_ESP_EYE)
  pinMode(13, INPUT_PULLUP);
  pinMode(14, INPUT_PULLUP);
#endif*/

  // camera init
  esp_err_t err = esp_camera_init(&config);
  if (err != ESP_OK) {
    blink_led_error();
    return STAT_ERR;
  }

  sensor_t * s = esp_camera_sensor_get();

  s->set_gain_ctrl(s, 1);                       // auto gain on 
  s->set_exposure_ctrl(s, 1);                   // auto exposure on 
  s->set_awb_gain(s, 1);                        // Auto White Balance enable (0 or 1)
  s->set_vflip(s,1);                            // vetical flip picture
  s->set_bpc(s, 1);                             // make dark pixels more black
  s->set_wpc(s, 1);                             // make bright pixels more white
  //s->set_gainceiling(s, (gainceiling_t)6); // 0 to 6

  /*s->set_brightness(s, 0); // -2 to 2
  s->set_contrast(s, 0); // -2 to 2
  s->set_saturation(s, 0); // -2 to 2
  s->set_whitebal(s, 1); // 0 = disable , 1 = enable
  s->set_awb_gain(s, 1); // 0 = disable , 1 = enable
  s->set_wb_mode(s, 0); // 0 to 4 - if awb_gain enabled (0 - Auto, 1 - Sunny, 2 - Cloudy, 3 - Office, 4 - Home)
  s->set_bpc(s, 1); // 0 = disable , 1 = enable
  s->set_wpc(s, 1); // 0 = disable , 1 = enable
//s->set_dcw(s, 0); //bad effect  0 = disable , 1 = enable*/

/*s->set_exposure_ctrl(s, 1); // 0 = disable , 1 = enable
  s->set_aec2(s, 0); // 0 = disable , 1 = enable
//s->set_ae_level(s, 2); // -2 to 2
//s->set_aec_value(s, 400); // 0 to 1200
  s->set_gain_ctrl(s, 0); // 0 = disable , 1 = enable
  s->set_agc_gain(s, 0); // 0 to 30
  s->set_gainceiling(s, (gainceiling_t)6); // 0 to 6
  s->set_raw_gma(s, 1); // 0 = disable , 1 = enable (makes much lighter and noisy)
  s->set_lenc(s, 0); // 0 = disable , 1 = enable
  s->set_hmirror(s, 0); // 0 = disable , 1 = enable
  s->set_vflip(s, 0); // 0 = disable , 1 = enable*/
  
  return STAT_OK;
}


void blink_led_active(){
  
  for(uint8_t i=0; i<3; i++){
    digitalWrite(LED_SHOT, ON);
    delay(100);
    digitalWrite(LED_SHOT, OFF);
    delay(100);
  }
}


void blink_led_error(){
  
  for(uint8_t i=0; i<3; i++){
    digitalWrite(LED_SHOT, ON);
    delay(1000);
    digitalWrite(LED_SHOT, OFF);
    delay(1000);
  }
}

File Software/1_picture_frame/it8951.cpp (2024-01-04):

#include <Arduino.h>
#include "it8951.h"
#include "spi.h"
#include "picture_frame.h"


//Built in I80 Command Code
#define IT8951_TCON_SYS_RUN      0x0001
#define IT8951_TCON_STANDBY      0x0002
#define IT8951_TCON_SLEEP        0x0003
#define IT8951_TCON_REG_RD       0x0010
#define IT8951_TCON_REG_WR       0x0011
#define IT8951_TCON_MEM_BST_RD_T 0x0012
#define IT8951_TCON_MEM_BST_RD_S 0x0013
#define IT8951_TCON_MEM_BST_WR   0x0014
#define IT8951_TCON_MEM_BST_END  0x0015
#define IT8951_TCON_LD_IMG       0x0020
#define IT8951_TCON_LD_IMG_AREA  0x0021
#define IT8951_TCON_LD_IMG_END   0x0022

//I80 User defined command code
#define USDEF_I80_CMD_DPY_AREA     0x0034
#define USDEF_I80_CMD_GET_DEV_INFO 0x0302
#define USDEF_I80_CMD_DPY_BUF_AREA 0x0037
//Panel active area 9.7"
#define IT8951_PANEL_WIDTH   1200//1024 //it Get Device information
#define IT8951_PANEL_HEIGHT   825//758

//Rotate mode
#define IT8951_ROTATE_0     0
#define IT8951_ROTATE_90    1
#define IT8951_ROTATE_180   2
#define IT8951_ROTATE_270   3

//Pixel mode , BPP - Bit per Pixel
#define IT8951_2BPP   0
#define IT8951_3BPP   1
#define IT8951_4BPP   2
#define IT8951_8BPP   3

//Waveform Mode
#define IT8951_MODE_0   0
#define IT8951_MODE_1   1
#define IT8951_MODE_2   2
#define IT8951_MODE_3   3
#define IT8951_MODE_4   4
//Endian Type
#define IT8951_LDIMG_L_ENDIAN   0
#define IT8951_LDIMG_B_ENDIAN   1
//Auto LUT
#define IT8951_DIS_AUTO_LUT   0
#define IT8951_EN_AUTO_LUT    1
//LUT Engine Status
#define IT8951_ALL_LUTE_BUSY 0xFFFF

//-----------------------------------------------------------------------
// IT8951 TCon Registers defines
//-----------------------------------------------------------------------
//Register Base Address
#define DISPLAY_REG_BASE 0x1000               //Register RW access for I80 only
//Base Address of Basic LUT Registers
#define LUT0EWHR  (DISPLAY_REG_BASE + 0x00)   //LUT0 Engine Width Height Reg
#define LUT0XYR   (DISPLAY_REG_BASE + 0x40)   //LUT0 XY Reg
#define LUT0BADDR (DISPLAY_REG_BASE + 0x80)   //LUT0 Base Address Reg
#define LUT0MFN   (DISPLAY_REG_BASE + 0xC0)   //LUT0 Mode and Frame number Reg
#define LUT01AF   (DISPLAY_REG_BASE + 0x114)  //LUT0 and LUT1 Active Flag Reg
//Update Parameter Setting Register
#define UP0SR (DISPLAY_REG_BASE + 0x134)      //Update Parameter0 Setting Reg

#define UP1SR     (DISPLAY_REG_BASE + 0x138)  //Update Parameter1 Setting Reg
#define LUT0ABFRV (DISPLAY_REG_BASE + 0x13C)  //LUT0 Alpha blend and Fill rectangle Value
#define UPBBADDR  (DISPLAY_REG_BASE + 0x17C)  //Update Buffer Base Address
#define LUT0IMXY  (DISPLAY_REG_BASE + 0x180)  //LUT0 Image buffer X/Y offset Reg
#define LUTAFSR   (DISPLAY_REG_BASE + 0x224)  //LUT Status Reg (status of All LUT Engines)

#define BGVR      (DISPLAY_REG_BASE + 0x250)  //Bitmap (1bpp) image color table
//-------System Registers----------------
#define SYS_REG_BASE 0x0000

//Address of System Registers
#define I80CPCR (SYS_REG_BASE + 0x04)
//-------Memory Converter Registers----------------
#define MCSR_BASE_ADDR 0x0200
#define MCSR (MCSR_BASE_ADDR  + 0x0000)
#define LISAR (MCSR_BASE_ADDR + 0x0008)

typedef struct
{
    uint16_t usPanelW;
    uint16_t usPanelH;
    uint16_t usImgBufAddrL;
    uint16_t usImgBufAddrH;
    uint16_t usFWVersion[8];   //16 Bytes String
    uint16_t usLUTVersion[8];   //16 Bytes String
}IT8951DevInfo;

typedef struct IT8951AreaImgInfo
{
    uint16_t usX;
    uint16_t usY;
    uint16_t usWidth;
    uint16_t usHeight;
}IT8951AreaImgInfo;

typedef struct IT8951LdImgInfo
{
    uint16_t usEndianType; //little or Big Endian
    uint16_t usPixelFormat; //bpp
    uint16_t usRotate; //Rotate mode
    uint32_t ulStartFBAddr; //Start address of source Frame buffer
    uint32_t ulImgBufBaseAddr;//Base address of target image buffer
    
}IT8951LdImgInfo;

IT8951DevInfo gstI80DevInfo;
uint8_t* gpFrameBuf;
uint32_t gulImgBufAddr;

#define SYS_REG_BASE 0x0000
#define I80CPCR (SYS_REG_BASE + 0x04)

#define USDEF_I80_CMD_GET_DEV_INFO 0x0302

#define IT8951_TCON_REG_WR       0x0011







//dsiplay//////////////////////////////////////////////////////////////////
uint8_t IT8951_Init()
{
  //bcm2835_spi_begin();
  //SPI.begin(SCK, MISO, MOSI, CS);
  //SPI.begin();
  //bcm2835_spi_setBitOrder(BCM2835_SPI_BIT_ORDER_MSBFIRST);    //default
  //SPI.setBitOrder(MSBFIRST);
  //bcm2835_spi_setDataMode(BCM2835_SPI_MODE0);                   //default
  //SPI.setDataMode(SPI_MODE0);
  //bcm2835_spi_setClockDivider(BCM2835_SPI_CLOCK_DIVIDER_32);    //default
  //SPI.setClockDivider(SPI_CLOCK_DIV8);

  // alternativ:
  //SPI.beginTransaction(SPISettings(20000000, MSBFIRST, SPI_MODE0));

  //bcm2835_gpio_fsel(CS, BCM2835_GPIO_FSEL_OUTP);
  pinMode(CS, OUTPUT);
  //bcm2835_gpio_fsel(HRDY, BCM2835_GPIO_FSEL_INPT);
  pinMode(HRDY, INPUT);
  //bcm2835_gpio_fsel(RESET, BCM2835_GPIO_FSEL_OUTP);
  pinMode(RESET, OUTPUT);
  
  digitalWrite(CS, HIGH);

  printf("****** IT8951 ******\n");

  digitalWrite(RESET, LOW);
  //bcm2835_delay(100);
  delay(300); //NOTE 100ms like in specs is not enough
  digitalWrite(RESET, HIGH);

  //Get Device Info
  GetIT8951SystemInfo(&gstI80DevInfo);

  Serial.print("W: ");
  Serial.print(gstI80DevInfo.usPanelW);
  Serial.print(" H: ");
  Serial.println(gstI80DevInfo.usPanelH);
  if (!gstI80DevInfo.usPanelW || !gstI80DevInfo.usPanelH) {
    return STAT_ERR;
  }

  gulImgBufAddr = gstI80DevInfo.usImgBufAddrL | ((uint32_t)gstI80DevInfo.usImgBufAddrH << 16);

  //Set to Enable I80 Packed mode
  IT8951WriteReg(I80CPCR, 0x0001);

  //SPI.endTransaction();

  return STAT_OK;
}

/*
extern IT8951DevInfo gstI80DevInfo;
extern uint8_t* gpFrameBuf;       //Host Source Frame buffer
extern uint32_t gulImgBufAddr;    //IT8951 Image buffer address
*/

//-----------------------------------------------------------
//Host controller function 1---Wait for host data Bus Ready
//-----------------------------------------------------------
void LCDWaitForReady()
{
  uint8_t ulData = digitalRead(HRDY);
  while(ulData == 0)
  {
    ulData = digitalRead(HRDY);
  }
}

//-----------------------------------------------------------
//Host controller function 2---Write command code to host data Bus
//-----------------------------------------------------------
void LCDWriteCmdCode(uint16_t usCmdCode)
{
  //Set Preamble for Write Command
  uint16_t wPreamble = 0x6000; 
  
  LCDWaitForReady();  

  digitalWrite(CS,LOW);
  
  spi.transfer(wPreamble>>8);
  spi.transfer(wPreamble);
  
  LCDWaitForReady();  
  
  spi.transfer(usCmdCode>>8);
  spi.transfer(usCmdCode);
  
  digitalWrite(CS,HIGH); 
}
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

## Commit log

2024-01-04 files modified
    [display_einsatz.stp, display_einsatz_v2.stp]
2024-01-04 changed files
    [hall_sensor_board-B_Cu.gbr, hall_sensor_board-B_Mask.gbr, hall_sensor_board-B_Paste.gbr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]
2024-01-05 spi clock, camer clock and camera frame for loop updated
